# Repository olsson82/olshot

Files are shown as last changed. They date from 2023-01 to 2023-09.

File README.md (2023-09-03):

# OlShot
This is an Arduino based Shooting game system. Free to use, you need to make the components your self.

It's wireless and uses nrf24l01 modules to communicate to the targets and the main system.

## How mutch does it cost to buid ?
Well it will cost you some money, for the components, and maufactoring the pcb, **BUT** to have your custom build game is priceless.

## Many Targets
If you are going to use many targets, you need to redesign main unit pcb to work with **ATmega2560** chip (same as in Arduino Mega)
The code here is by default set for 5 targets, but you can adjust it. Test the code in Arduino software when you change to see if your amount of targets
is accepted.

# Read more
* [Wiki](https://github.com/olsson82/olshot/wiki)
* [Targets](page/targets.md)
* [Main Unit](page/mainunit.md)

## Updates
**2023-09-01: Did a redesign on the Nextion Screen. Files uploaded**

**2023-08-31: The clock function is now added to the code, and some adjustments done in the code**

**2023-08-30: The first BETA version of main unit is released.**

**2023-08-04: Working on the code for main unit and design for the touchscreen.**

### Main Unit
**2023-08-01: Kicad files now uploaded**

**2023-07-31: The main unit has been tested and everything seems to be working. The kicad files will soon be uploaded.**

<figure>
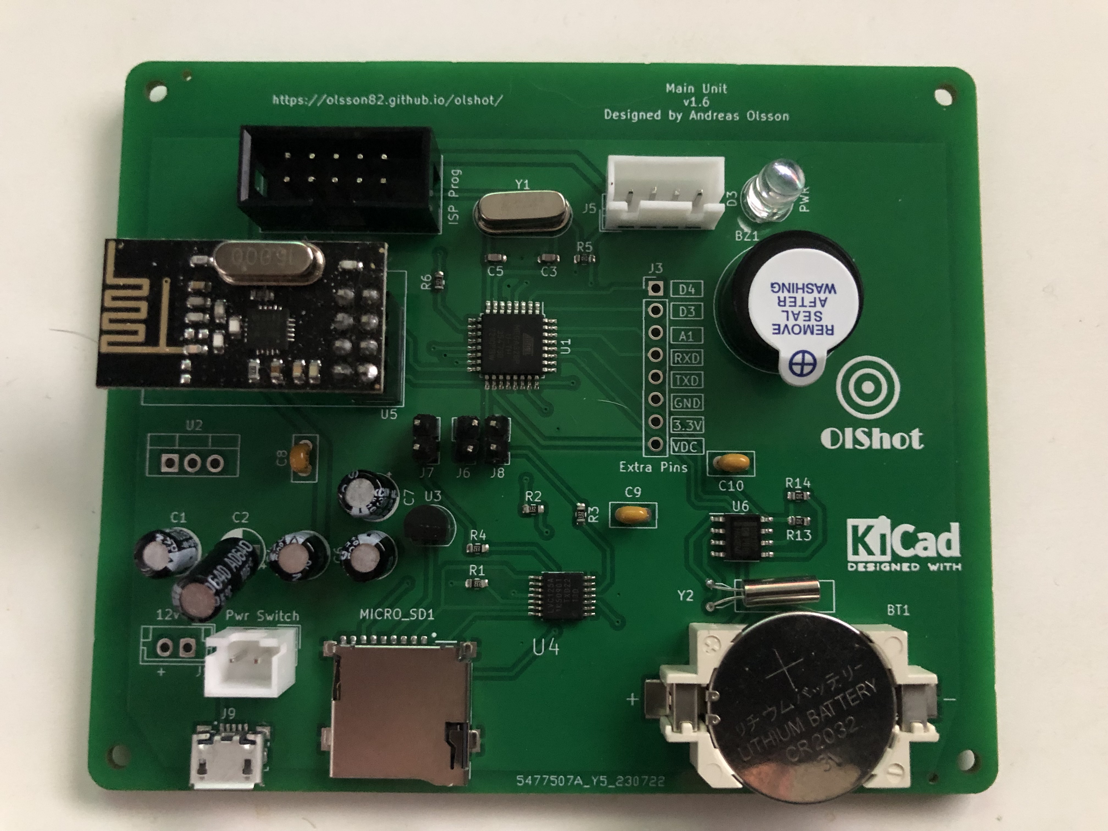
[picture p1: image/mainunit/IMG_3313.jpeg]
    
    <figcaption>Front side of the PCB.</figcaption>
</figure>

### Target PCB
**2023-02-05: The Target PCB Is now avalible for kicad and arduino code.**

Did a redesign of the target sensor, everything is now on the top side. Added jst connections instead of soldering.
<figure>
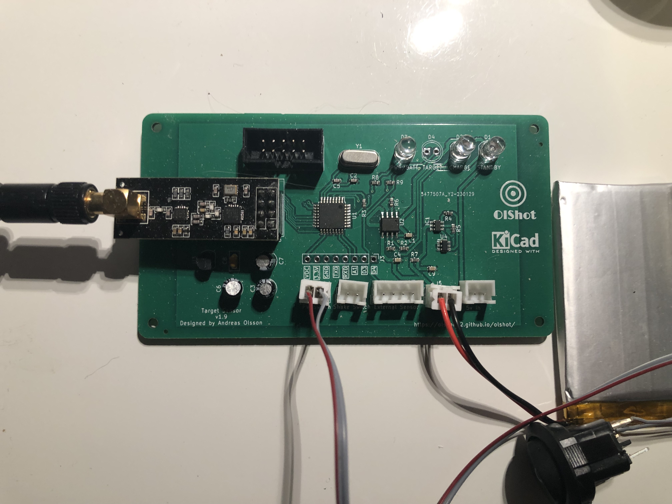
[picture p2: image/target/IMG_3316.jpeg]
    
    <figcaption>Front side of the PCB.</figcaption>
</figure>

## Discuss
Feel free to take part in this project. Go to [Discussion](https://github.com/olsson82/olshot/discussions) to ask questions or discuss about the project.

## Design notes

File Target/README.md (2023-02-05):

# Target Sensor Code
This is the target sensor code. When uploading with the ISP programmer, select Arduino Nano as board and programmer USBasp, then under sketch use **upload with programmer**

Change **targID** and **sendID** to unique id numbers.

During test you can have **#define DEBUG** enabled for serial output. Not recommended when you are going to use the sensors live.

If you need to change the fail safe time change in **myDesiredTime**

During test have the **PALevel** set to **RF24_PA_MIN** and then you can use **RF24_PA_MAX** when you go live. When you have them close during test, it is recommended to have them on min.

## Your code
If you have other version of the target sensor, share them with us.

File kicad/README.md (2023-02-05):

# Kicad Files

This is the place you will find KiCad files.

They are designed in KiCad 6

Inside Library folder you find custom footprints that needed. 

## Use of files
You are free to do changes and copy to your custom builds if you want.

You can also use them without changes. You are not allowed to use my design as is to make money on it.

There a lot of hours spent on develop this so, use it but don't be a millionare on it.

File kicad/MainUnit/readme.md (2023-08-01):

# Main Unit
This is the main unit. You also need target sensors for it to work.
Please read the WIKI about this main unit before manufactor so you know everything.

Good luck!

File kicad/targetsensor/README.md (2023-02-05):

# Target Sensor
This is the target sensor. You also need the main unit for it to work.
Please read the WIKI about this sensors before manufactor so you know everything.

Good luck!

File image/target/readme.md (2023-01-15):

# Image for targets

Here is a place for image for target sensors.

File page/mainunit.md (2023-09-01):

# Main Unit

The main unit is the big brain in all this. It is based on the ATmega328 chip that you will find in example arduino nano. The main unit has:

* SD Card Reader
* USB Powered (Runs from powerbank)
* Nextion display (For all controls)
* Buzzer
* Built in RTC for time.

## How it works
You control everything from the Nextion Display. You can setup all settings from the Settings Page, like targets, how many players and so on.
Select a game and start playing. The main unit will send out to the right target to get ready for the hit mode. When target is returning, a new target will be selected.

Targets are selected randomly, so you never know what target will light. Also in Quicktime mode the time is randomly selected so you don't know when the new target will light up.

## The Games
There are three games to play:

### Quicktime
You can have up to 10 rounds, and you need to shoot fast when the target lights up. The time between the rounds are randomly selected. Shoot fast!

### Rapidfire
You set the total shots needed, then you need to shoot fast! So if you set 20 shots, you need to shoot them realy fast!

### Timed mode
You set the time to play, then shot so many targets you can on that time.

## PCB
All files for manufacture is avalible and the main unit will look like this:

<figure>
    Main Unit
    <figcaption>The Main Unit PCB.</figcaption>
</figure>

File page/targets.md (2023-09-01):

# Wireless Targets

The wireless targets are battery powered and runs on LiPo battery. They use ATMega328P-AU Chip that is in arduino nano. But you can use any Arduino.

## How it works
When the main unit trigger the target sensor, they will wait until vibration starts from an vibration sensor. Normaly you place it on behind the target. And they will send back that they have been trigged.

Each sensor has it unique code, one for recive data, and one for send data, so they know when they are going to be activated.

When the main unit trigger the sensor a **blue** light will be activated, to inform the shooter that it is time to shoot.

## PCB
All files for making the target sensor is avalible and it will look like this:

<figure>
    Target Sensor
    <figcaption>The Target Sensor PCB.</figcaption>
</figure>

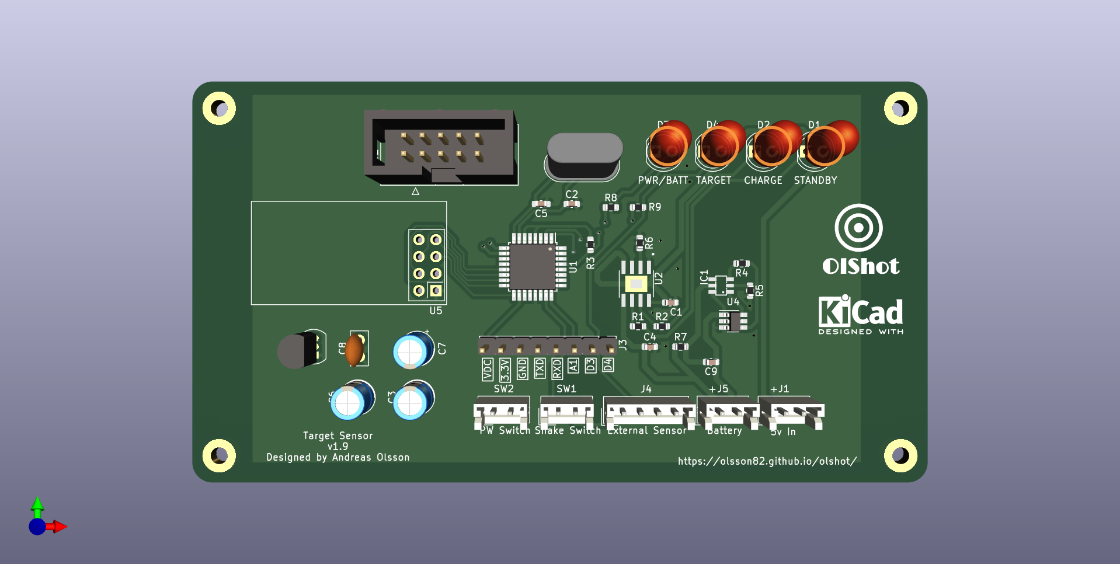
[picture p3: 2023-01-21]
image/target/targetsensor-front.png

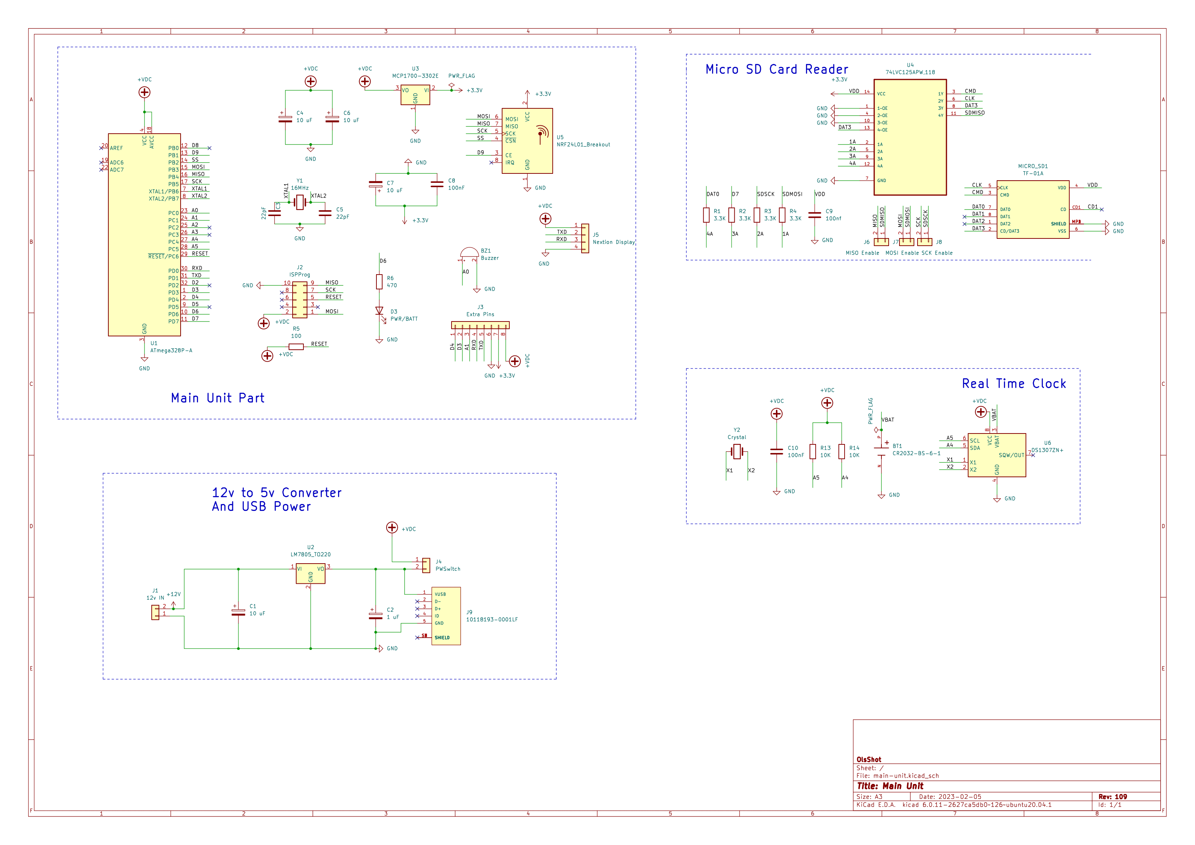
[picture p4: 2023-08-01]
image/mainunit/mainunit.png

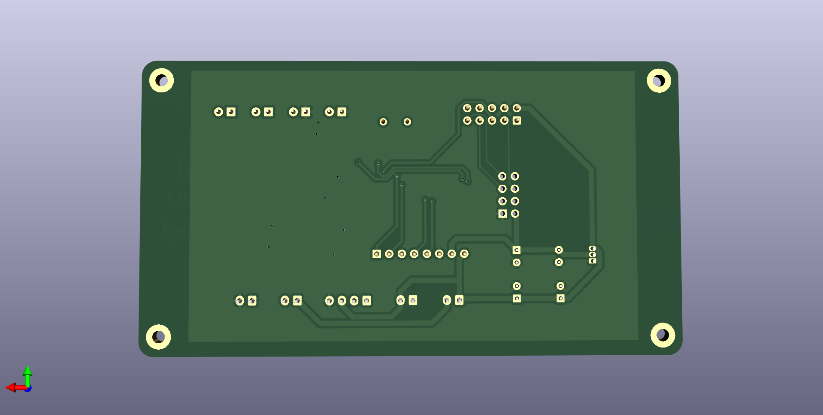
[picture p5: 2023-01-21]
image/target/targetsensor-back.png

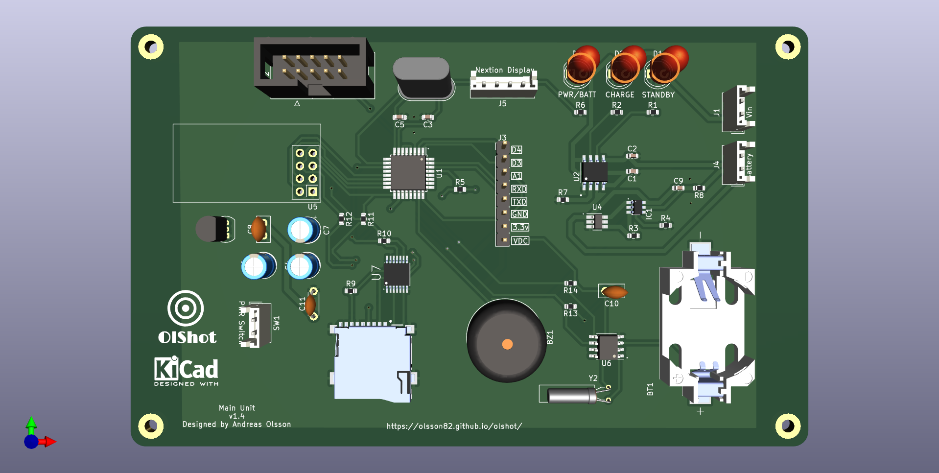
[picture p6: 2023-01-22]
image/mainunit/main-unit.png

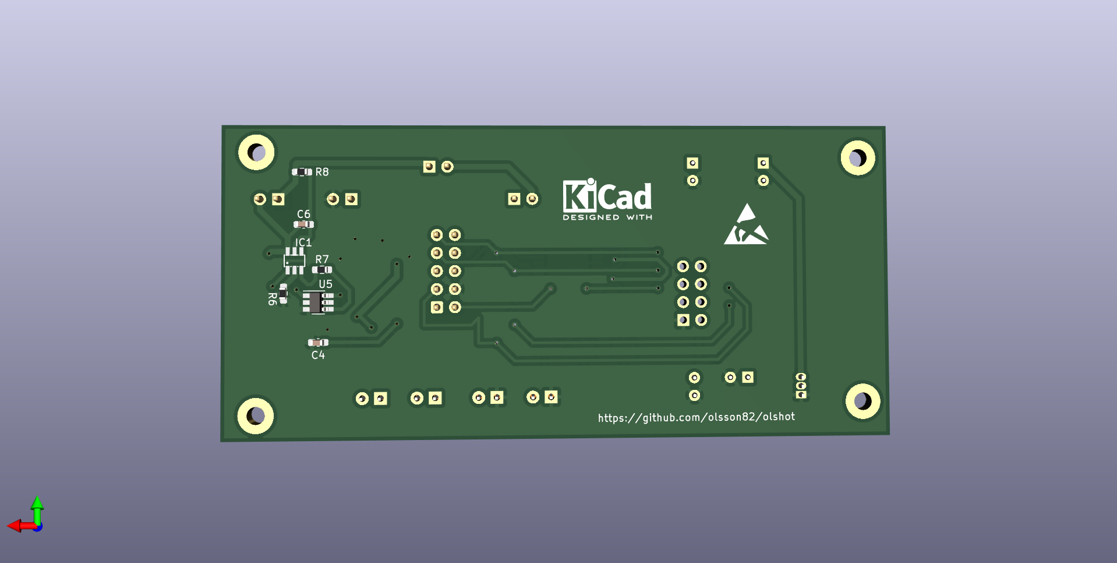
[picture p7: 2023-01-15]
image/target/shootingsensor_back.png

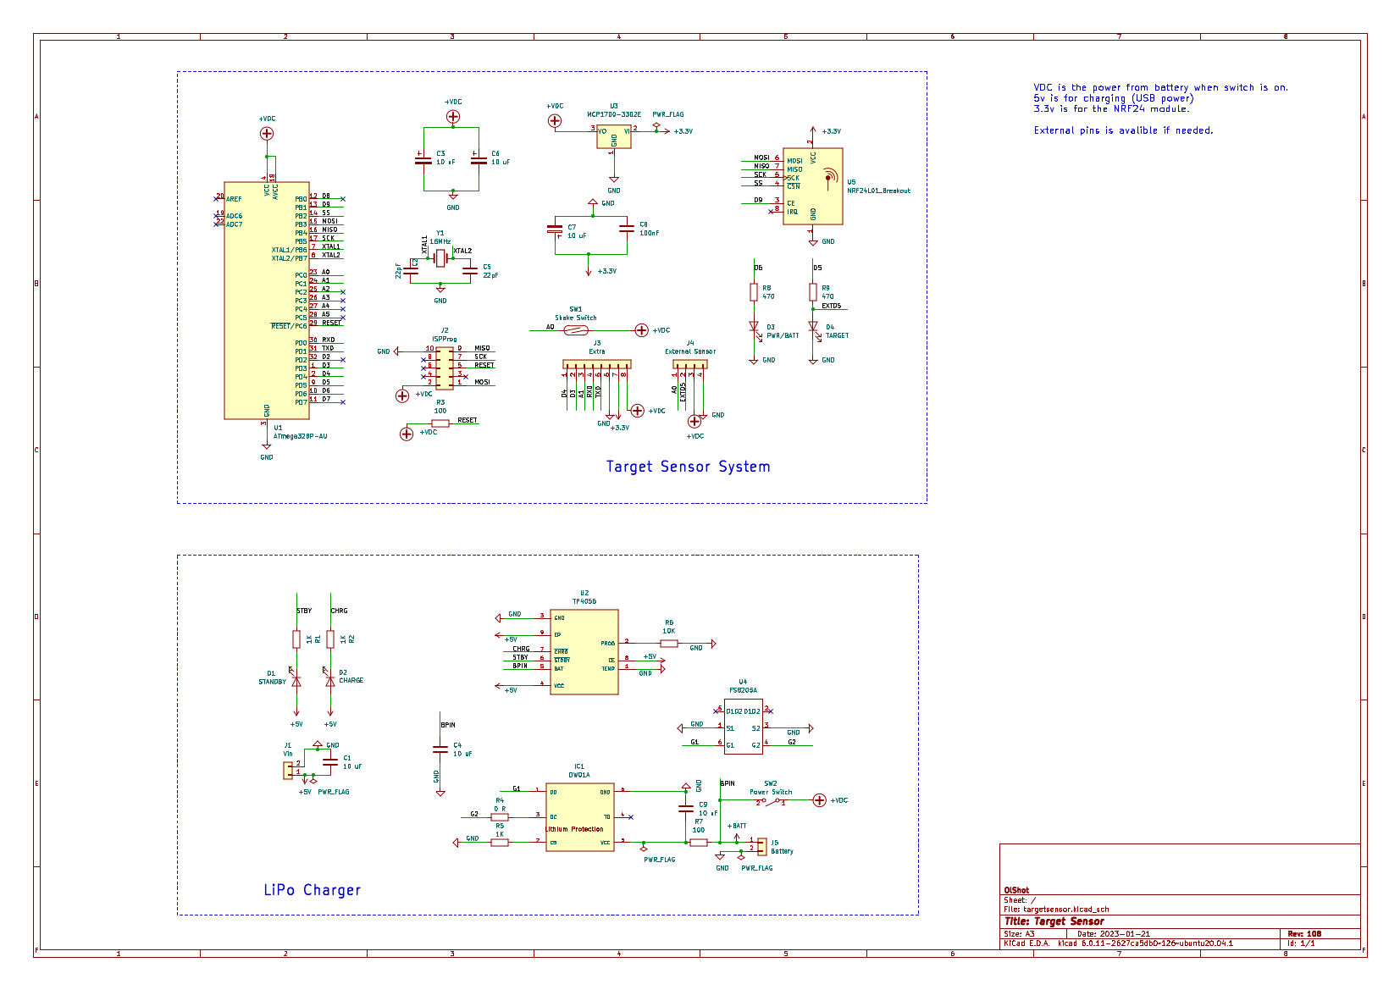
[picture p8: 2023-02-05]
image/target/targetsensor.png

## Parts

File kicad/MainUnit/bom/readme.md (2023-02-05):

# Soldering helper.
An helper for you when you soldering the board.

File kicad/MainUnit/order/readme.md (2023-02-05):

# For order
If you just need to order pcb this files is what you need.

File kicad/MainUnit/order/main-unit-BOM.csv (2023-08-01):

Comment | Designator | Footprint | LCSC Part Number
CR2032-BS-6-1 | BT1 | BAT_CR2032-BS-6-1 | C70377
22pF | C3,C5 | Capacitor_SMD:C_0603_1608Metric | C1653
10118193-0001LF | J9 | 10118193-0001LF:FCI_10118193-0001LF | C381144
TF-01A | MICRO_SD1 | TF-01A | C91145
3.3K | R1,R2,R3,R4 | Resistor_SMD:R_0603_1608Metric | C22978
10K | R13,R14 | Resistor_SMD:R_0603_1608Metric | C25804
100 | R5 | Resistor_SMD:R_0603_1608Metric | C22775
470 | R6 | Resistor_SMD:R_0603_1608Metric | C23179
ATmega328P-A | U1 | Package_QFP:TQFP-32_7x7mm_P0.8mm | C14877
74LVC125APW,118 | U4 | 74LVC125APW_118:SOP65P640X110-14N | C6059
DS1307ZN+ | U6 | Package_SO:SOIC-8_3.9x4.9mm_P1.27mm | C356706

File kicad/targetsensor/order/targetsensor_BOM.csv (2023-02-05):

Comment | Designator | Footprint | LCSC Part Number
10 uF | C1,C4,C9 | Capacitor_SMD:C_0603_1608Metric | C96446
22pF | C2,C5 | Capacitor_SMD:C_0603_1608Metric | C1653
DW01A | IC1 | SOT23-6 | C181096
1K | R1,R2,R5 | Resistor_SMD:R_0603_1608Metric | C21190
100 | R3,R7 | Resistor_SMD:R_0603_1608Metric | C22775
0 R | R4 | Resistor_SMD:R_0603_1608Metric | C21189
10K | R6 | Resistor_SMD:R_0603_1608Metric | C25804
470 | R8,R9 | Resistor_SMD:R_0603_1608Metric | C23179
ATmega328P-A | U1 | Package_QFP:TQFP-32_7x7mm_P0.8mm | C14877
TP4056 | U2 | SOP127P600X175-9N | C16581
FS8205A | U4 | Package_TO_SOT_SMD:SOT-23-6 | C2830320

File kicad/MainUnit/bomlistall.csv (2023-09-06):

Component Count: | 39
Ref | Qnty | Value | Cmp name | Footprint | Description
BT1, | 1 | CR2032-BS-6-1 | CR2032-BS-6-1 | BAT_CR2032-BS-6-1
BZ1, | 1 | Buzzer | Buzzer | Buzzer_Beeper:Buzzer_15x7.5RM7.6 | Buzzer, polarized
C1, C4, C6, C7, | 4 | 10 uF | C_Polarized | Capacitor_THT:CP_Radial_D5.0mm_P2.50mm | Polarized capacitor
C2, | 1 | 1 uF | C_Polarized | Capacitor_THT:CP_Radial_D5.0mm_P2.50mm | Polarized capacitor
C3, C5, | 2 | 22pF | C | Capacitor_SMD:C_0603_1608Metric | Unpolarized capacitor
C8, C10, | 2 | 100nF | C | Capacitor_THT:C_Disc_D5.0mm_W2.5mm_P2.50mm | Unpolarized capacitor
C9, | 1 | 100nf | C | Capacitor_THT:C_Disc_D5.0mm_W2.5mm_P2.50mm | Unpolarized capacitor
D3, | 1 | PWR/BATT | LED | LED_THT:LED_D5.0mm | Light emitting diode
J1, | 1 | 12v IN | Conn_01x02 | Connector_JST:JST_EH_B2B-EH-A_1x02_P2.50mm_Vertical | Generic connector, single row, 01x02, script generated (kicad-library-utils/schlib/autogen/connector/)
J2, | 1 | ISPProg | Conn_02x05_Odd_Even | Connector_IDC:IDC-Header_2x05_P2.54mm_Vertical | Generic connector, double row, 02x05, odd/even pin numbering scheme (row 1 odd numbers, row 2 even numbers), script generated (kicad-library-utils/schlib/autogen/connector/)
J3, | 1 | Extra Pins | Conn_01x08 | Connector_PinHeader_2.54mm:PinHeader_1x08_P2.54mm_Vertical | Generic connector, single row, 01x08, script generated (kicad-library-utils/schlib/autogen/connector/)
J4, | 1 | PWSwitch | Conn_01x02 | Connector_JST:JST_EH_B2B-EH-A_1x02_P2.50mm_Vertical | Generic connector, single row, 01x02, script generated (kicad-library-utils/schlib/autogen/connector/)
J5, | 1 | Nextion Display | Conn_01x04 | Connector_JST:JST_EH_B4B-EH-A_1x04_P2.50mm_Vertical | Generic connector, single row, 01x04, script generated (kicad-library-utils/schlib/autogen/connector/)
J6, | 1 | MISO Enable | Conn_01x02 | Connector_PinHeader_2.54mm:PinHeader_1x02_P2.54mm_Vertical | Generic connector, single row, 01x02, script generated (kicad-library-utils/schlib/autogen/connector/)
J7, | 1 | MOSI Enable | Conn_01x02 | Connector_PinHeader_2.54mm:PinHeader_1x02_P2.54mm_Vertical | Generic connector, single row, 01x02, script generated (kicad-library-utils/schlib/autogen/connector/)
J8, | 1 | SCK Enable | Conn_01x02 | Connector_PinHeader_2.54mm:PinHeader_1x02_P2.54mm_Vertical | Generic connector, single row, 01x02, script generated (kicad-library-utils/schlib/autogen/connector/)
J9, | 1 | 10118193-0001LF | 10118193-0001LF | 10118193-0001LF:FCI_10118193-0001LF
MICRO_SD1, | 1 | TF-01A | TF-01A | TF-01A
R1, R2, R3, R4, | 4 | 3.3K | R | Resistor_SMD:R_0603_1608Metric | Resistor
R5, | 1 | 100 | R | Resistor_SMD:R_0603_1608Metric | Resistor
R6, | 1 | 470 | R | Resistor_SMD:R_0603_1608Metric | Resistor
R13, R14, | 2 | 10K | R | Resistor_SMD:R_0603_1608Metric | Resistor
U1, | 1 | ATmega328P-A | ATmega328P-A | Package_QFP:TQFP-32_7x7mm_P0.8mm | 20MHz, 32kB Flash, 2kB SRAM, 1kB EEPROM, TQFP-32
U2, | 1 | LM7805_TO220 | LM7805_TO220 | Package_TO_SOT_THT:TO-220-3_Vertical | Positive 1A 35V Linear Regulator, Fixed Output 5V, TO-220
U3, | 1 | MCP1700-3302E | MCP1700x-330xxTO | Package_TO_SOT_THT:TO-92_Inline | 250mA Low Quiscent Current LDO, 3.3V output, TO-92
U4, | 1 | 74LVC125APW,118 | 74LVC125APW,118 | 74LVC125APW_118:SOP65P640X110-14N
U5, | 1 | NRF24L01_Breakout | NRF24L01_Breakout | RF_Module:nRF24L01_Breakout | Ultra low power 2.4GHz RF Transceiver, Carrier PCB
U6, | 1 | DS1307ZN+ | DS1307ZN+ | Package_SO:SOIC-8_3.9x4.9mm_P1.27mm | 64 x 8, Serial, I2C Real-time clock, 4.5V to 5.5V VCC, -40°C to +85°C, SOIC-8
Y1, | 1 | 16MHz | Crystal | Crystal:Crystal_HC18-U_Vertical | Two pin crystal
Y2, | 1 | 32.768kHz | Crystal | Crystal:Crystal_AT310_D3.0mm_L10.0mm_Horizontal | Two pin crystal

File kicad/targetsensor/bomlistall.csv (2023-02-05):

Component Count: | 36
Ref | Qnty | Value | Cmp name | Footprint | Description | Vendor
C1, C4, C9, | 3 | 10 uF | C | Capacitor_SMD:C_0603_1608Metric | Unpolarized capacitor
C2, C5, | 2 | 22pF | C | Capacitor_SMD:C_0603_1608Metric | Unpolarized capacitor
C3, C6, C7, | 3 | 10 uF | C_Polarized | Capacitor_THT:CP_Radial_D5.0mm_P2.50mm | Polarized capacitor
C8, | 1 | 100nF | C | Capacitor_THT:C_Disc_D5.0mm_W2.5mm_P2.50mm | Unpolarized capacitor
D1, | 1 | STANDBY | LED | LED_THT:LED_D5.0mm | Light emitting diode
D2, | 1 | CHARGE | LED | LED_THT:LED_D5.0mm | Light emitting diode
D3, | 1 | PWR/BATT | LED | LED_THT:LED_D5.0mm | Light emitting diode
D4, | 1 | TARGET | LED | LED_THT:LED_D5.0mm | Light emitting diode
IC1, | 1 | DW01A | DW01A | SOT23-6
J1, | 1 | Vin | Conn_01x02 | Connector_JST:JST_EH_B2B-EH-A_1x02_P2.50mm_Vertical | Generic connector, single row, 01x02, script generated (kicad-library-utils/schlib/autogen/connector/)
J2, | 1 | ISPProg | Conn_02x05_Odd_Even | Connector_IDC:IDC-Header_2x05_P2.54mm_Vertical | Generic connector, double row, 02x05, odd/even pin numbering scheme (row 1 odd numbers, row 2 even numbers), script generated (kicad-library-utils/schlib/autogen/connector/)
J3, | 1 | Extra | Conn_01x08 | Connector_PinHeader_2.54mm:PinHeader_1x08_P2.54mm_Vertical | Generic connector, single row, 01x08, script generated (kicad-library-utils/schlib/autogen/connector/)
J4, | 1 | External Sensor | Conn_01x04 | Connector_JST:JST_EH_B4B-EH-A_1x04_P2.50mm_Vertical | Generic connector, single row, 01x04, script generated (kicad-library-utils/schlib/autogen/connector/)
J5, | 1 | Battery | Conn_01x02 | Connector_JST:JST_EH_B2B-EH-A_1x02_P2.50mm_Vertical | Generic connector, single row, 01x02, script generated (kicad-library-utils/schlib/autogen/connector/)
R1, R2, R5, | 3 | 1K | R | Resistor_SMD:R_0603_1608Metric | Resistor
R3, R7, | 2 | 100 | R | Resistor_SMD:R_0603_1608Metric | Resistor
R4, | 1 | 0 R | R | Resistor_SMD:R_0603_1608Metric | Resistor
R6, | 1 | 10K | R | Resistor_SMD:R_0603_1608Metric | Resistor
R8, R9, | 2 | 470 | R | Resistor_SMD:R_0603_1608Metric | Resistor
SW1, | 1 | Shake Switch | SW_Reed | Connector_JST:JST_EH_B2B-EH-A_1x02_P2.50mm_Vertical | reed switch
SW2, | 1 | Power Switch | SW_SPST | Connector_JST:JST_EH_B2B-EH-A_1x02_P2.50mm_Vertical | Single Pole Single Throw (SPST) switch
U1, | 1 | ATmega328P-AU | ATmega328P-A | Package_QFP:TQFP-32_7x7mm_P0.8mm | 20MHz, 32kB Flash, 2kB SRAM, 1kB EEPROM, TQFP-32
U2, | 1 | TP4056 | TP4056 | SOP127P600X175-9N
U3, | 1 | MCP1700-3302E | MCP1700x-330xxTO | Package_TO_SOT_THT:TO-92_Inline | 250mA Low Quiscent Current LDO, 3.3V output, TO-92
U4, | 1 | FS8205A | FS8205A | Package_TO_SOT_SMD:SOT-23-6 | FS8205A
U5, | 1 | NRF24L01_Breakout | NRF24L01_Breakout | RF_Module:nRF24L01_Breakout | Ultra low power 2.4GHz RF Transceiver, Carrier PCB
Y1, | 1 | 16MHz | Crystal | Crystal:Crystal_HC18-U_Vertical | Two pin crystal

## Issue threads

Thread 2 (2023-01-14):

PCB For Shooting Sensors

olsson82, 2023-01-14:
# PCB
Make an PCB for the shooting sensor, with built in lipo charger.

olsson82, 2023-01-14:
NRF24 Will be module based, so it possible to choose with or without external antenna.

olsson82, 2023-01-18:
Add some extra connections for pins, and battery contact.

olsson82, 2023-02-05:
Work on it is done!

Closed 2023-02-05.

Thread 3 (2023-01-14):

Develop of Target Sensors

olsson82, 2023-01-14:
Develop the arduino code for the target sensors. They communicate thru nrf24 modules wireless.

olsson82, 2023-01-14:
Started working on the code, not done yet but a part of it is here. 230d5bd9a5e34640cc30d04f9cab19dd336314a9

olsson82, 2023-02-05:
The code is now avalible 1b19e92

Closed 2023-02-05.

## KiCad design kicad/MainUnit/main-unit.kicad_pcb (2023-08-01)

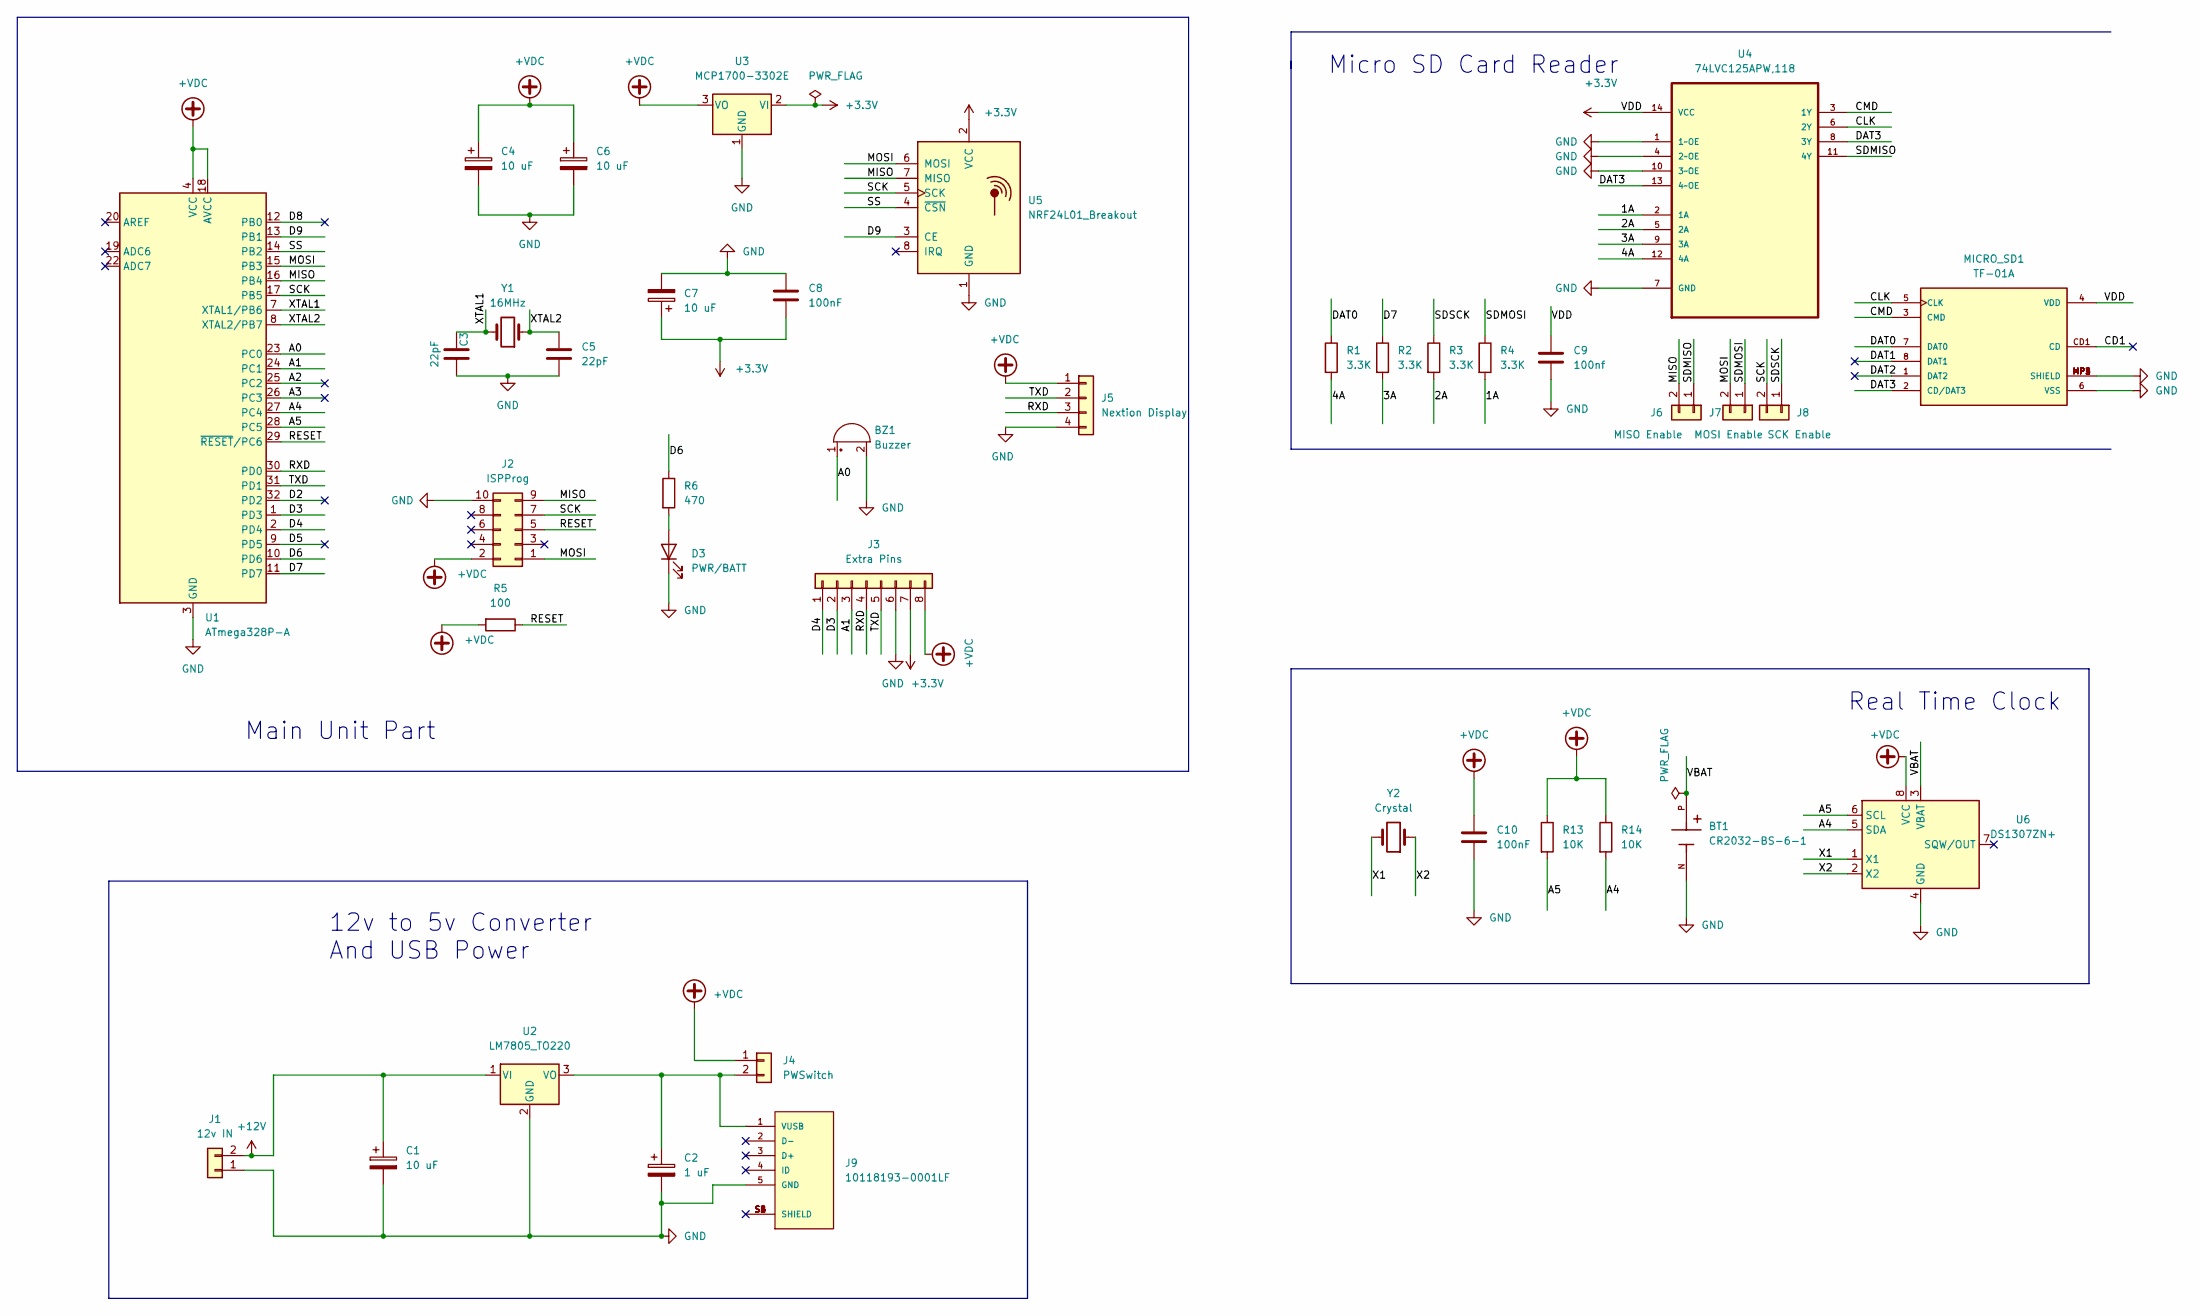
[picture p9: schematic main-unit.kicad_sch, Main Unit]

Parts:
BT1: CR2032-BS-6-1; BAT_CR2032-BS-6-1; PARTREV 2011/2/14; LCSC C70377
BZ1: Buzzer; Buzzer_15x7.5RM7.6
C1, C4, C6, C7: 10 uF; CP_Radial_D5.0mm_P2.50mm
C2: 1 uF; CP_Radial_D5.0mm_P2.50mm
C3, C5: 22pF; C_0603_1608Metric; LCSC C1653
C8, C10: 100nF; C_Disc_D5.0mm_W2.5mm_P2.50mm
C9: 100nf; C_Disc_D5.0mm_W2.5mm_P2.50mm
D3: PWR/BATT; LED_D5.0mm
J1: 12v IN; JST_EH_B2B-EH-A_1x02_P2.50mm_Vertical
J2: ISPProg; IDC-Header_2x05_P2.54mm_Vertical
J3: Extra Pins; PinHeader_1x08_P2.54mm_Vertical
J4: PWSwitch; JST_EH_B2B-EH-A_1x02_P2.50mm_Vertical
J5: Nextion Display; JST_EH_B4B-EH-A_1x04_P2.50mm_Vertical
J6: MISO Enable; PinHeader_1x02_P2.54mm_Vertical
J7: MOSI Enable; PinHeader_1x02_P2.54mm_Vertical
J8: SCK Enable; PinHeader_1x02_P2.54mm_Vertical
J9: 10118193-0001LF; FCI_10118193-0001LF; LCSC C381144
MICRO_SD1: TF-01A; LCSC C91145
R1, R2, R3, R4: 3.3K; R_0603_1608Metric; LCSC C22978
R5: 100; R_0603_1608Metric; LCSC C22775
R6: 470; R_0603_1608Metric; LCSC C23179
R13, R14: 10K; R_0603_1608Metric; LCSC C25804
U1: ATmega328P-A; TQFP-32_7x7mm_P0.8mm; LCSC C14877
U2: LM7805_TO220; TO-220-3_Vertical
U3: MCP1700-3302E; TO-92_Inline
U4: 74LVC125APW,118; SOP65P640X110-14N; MPN 74LVC125APW,118; LCSC C6059
U5: NRF24L01_Breakout; nRF24L01_Breakout
U6: DS1307ZN+; SOIC-8_3.9x4.9mm_P1.27mm; LCSC C356706
Y1: 16MHz; Crystal_HC18-U_Vertical
Y2: Crystal; Crystal_AT310_D3.0mm_L10.0mm_Horizontal

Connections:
+3.3V: C7.1, C8.2, C9.1, J3.7, MICRO_SD1.4 (VDD), U3.2 (VI), U4.14 (VCC), U5.2 (VCC)
+12V: C1.1, J1.2, U2.1 (VI)
+VDC: C4.1, C6.1, C10.2, J2.2, J3.8, J4.1, J5.1, R5.2, R13.1, R14.1, U1.4 (VCC), U1.6 (VCC), U1.18 (AVCC), U3.3 (VO), U6.8 (VCC)
/1A: R4.2, U4.2 (1A)
/2A: R3.2, U4.5 (2A)
/3A: R2.2, U4.9 (3A)
/4A: R1.2, U4.12 (4A)
/A0: BZ1.1 (-), U1.23 (PC0)
/A1: J3.3, U1.24 (PC1)
/A2: U1.25 (PC2)
/A3: U1.26 (PC3)
/A4: R14.2, U1.27 (PC4), U6.5 (SDA)
/A5: R13.2, U1.28 (PC5), U6.6 (SCL)
/CD1: MICRO_SD1.CD1 (CD)
/CLK: MICRO_SD1.5 (CLK), U4.6 (2Y)
/CMD: MICRO_SD1.3 (CMD), U4.3 (1Y)
/D2: U1.32 (PD2)
/D3: J3.2, U1.1 (PD3)
/D4: J3.1, U1.2 (PD4)
/D5: U1.9 (PD5)
/D6: R6.1, U1.10 (PD6)
/D7: R2.1, U1.11 (PD7)
/D8: U1.12 (PB0)
/D9: U1.13 (PB1), U5.3 (CE)
/DAT0: MICRO_SD1.7 (DAT0), R1.1
/DAT1: MICRO_SD1.8 (DAT1)
/DAT2: MICRO_SD1.1 (DAT2)
/DAT3: MICRO_SD1.2 (CD/DAT3), U4.8 (3Y), U4.13 (4~OE)
/MISO: J2.9, J6.2, U1.16 (PB4), U5.7 (MISO)
/MOSI: J2.1, J7.2, U1.15 (PB3), U5.6 (MOSI)
/RESET: J2.5, R5.1, U1.29 (~RESET/PC6)
/RXD: J3.4, J5.3, U1.30 (PD0)
/SCK: J2.7, J8.2, U1.17 (PB5), U5.5 (SCK)
/SDMISO: J6.1, U4.11 (4Y)
/SDMOSI: J7.1, R4.1
/SDSCK: J8.1, R3.1
/SS: U1.14 (PB2), U5.4 (~CSN)
/TXD: J3.5, J5.2, U1.31 (PD1)
/VBAT: BT1.P, U6.3 (VBAT)
/X1: U6.1 (X1), Y2.2
/X2: U6.2 (X2), Y2.1
/XTAL1: C3.1, U1.7 (XTAL1/PB6), Y1.2
/XTAL2: C5.2, U1.8 (XTAL2/PB7), Y1.1
GND: BT1.N, BZ1.2 (+), C1.2, C2.2, C3.2, C4.2, C5.1, C6.2, C7.2, C8.1, C9.2, C10.1, D3.1 (K), J1.1, J2.10, J3.6, J5.4, J9.5 (GND), MICRO_SD1.6 (VSS), MICRO_SD1.MP1 (SHIELD), MICRO_SD1.MP2 (SHIELD), MICRO_SD1.MP3 (SHIELD), MICRO_SD1.MP4 (SHIELD), U1.3 (GND), U1.5 (GND), U1.21 (GND), U2.2 (GND), U3.1 (GND), U4.1 (1~OE), U4.4 (2~OE), U4.7 (GND), U4.10 (3~OE), U5.1 (GND), U6.4 (GND)
unnamed: C2.1, J4.2, J9.1 (VUSB), U2.3 (VO)
unnamed: D3.2 (A), R6.2

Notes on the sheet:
Micro SD Card Reader
Main Unit Part
12v to 5v Converter And USB Power
Real Time Clock

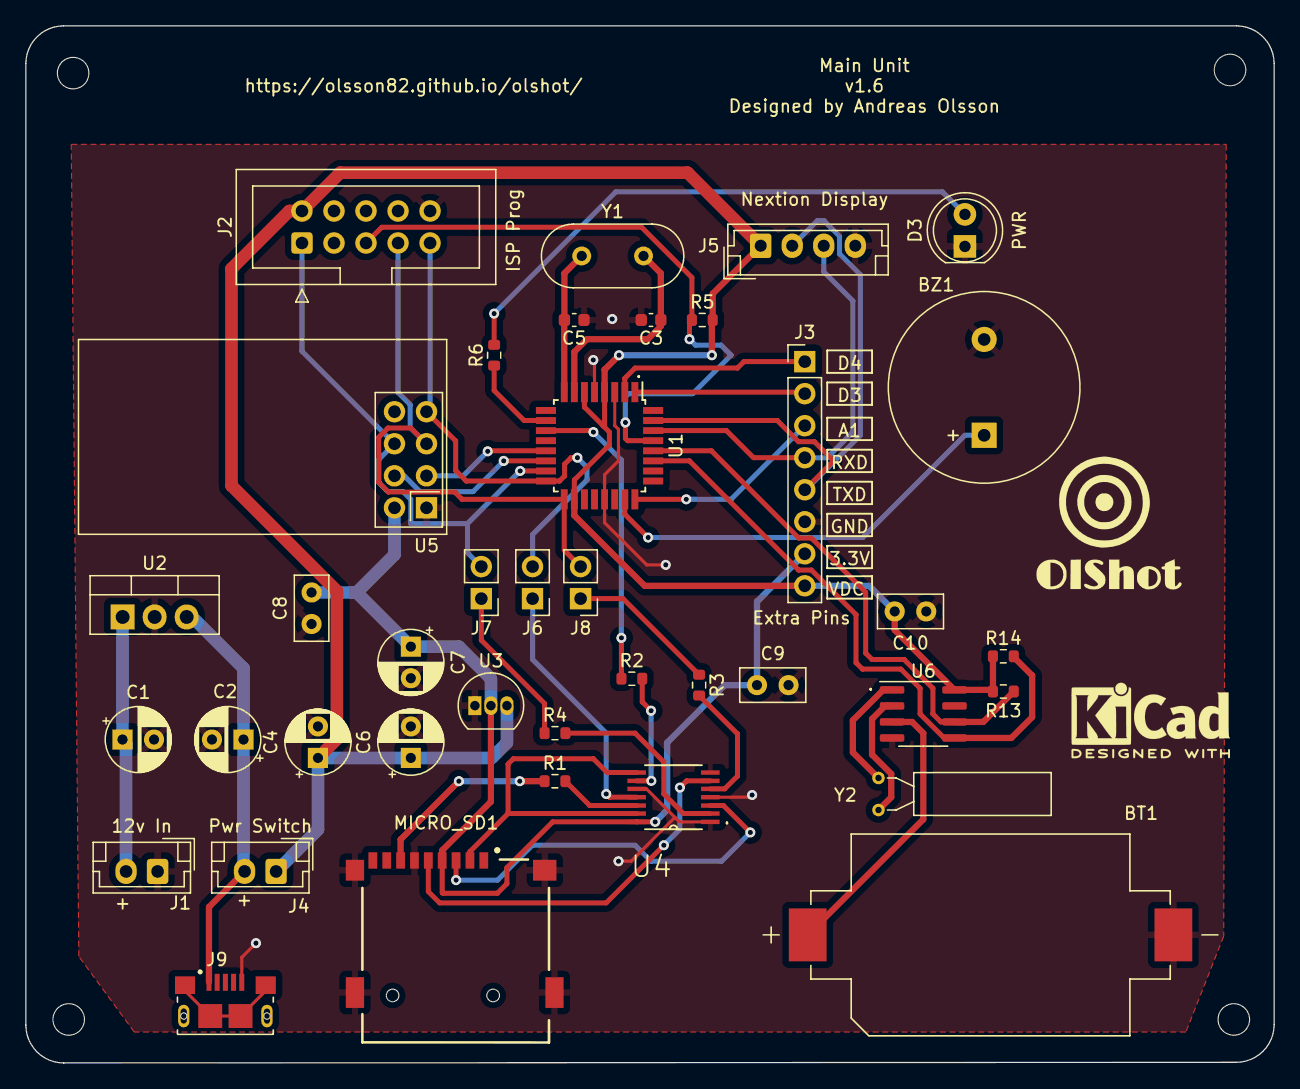
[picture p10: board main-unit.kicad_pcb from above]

Board: 2 copper layers, 99.0 x 82.2 mm, 39 parts (0 on the bottom side), 38 nets.

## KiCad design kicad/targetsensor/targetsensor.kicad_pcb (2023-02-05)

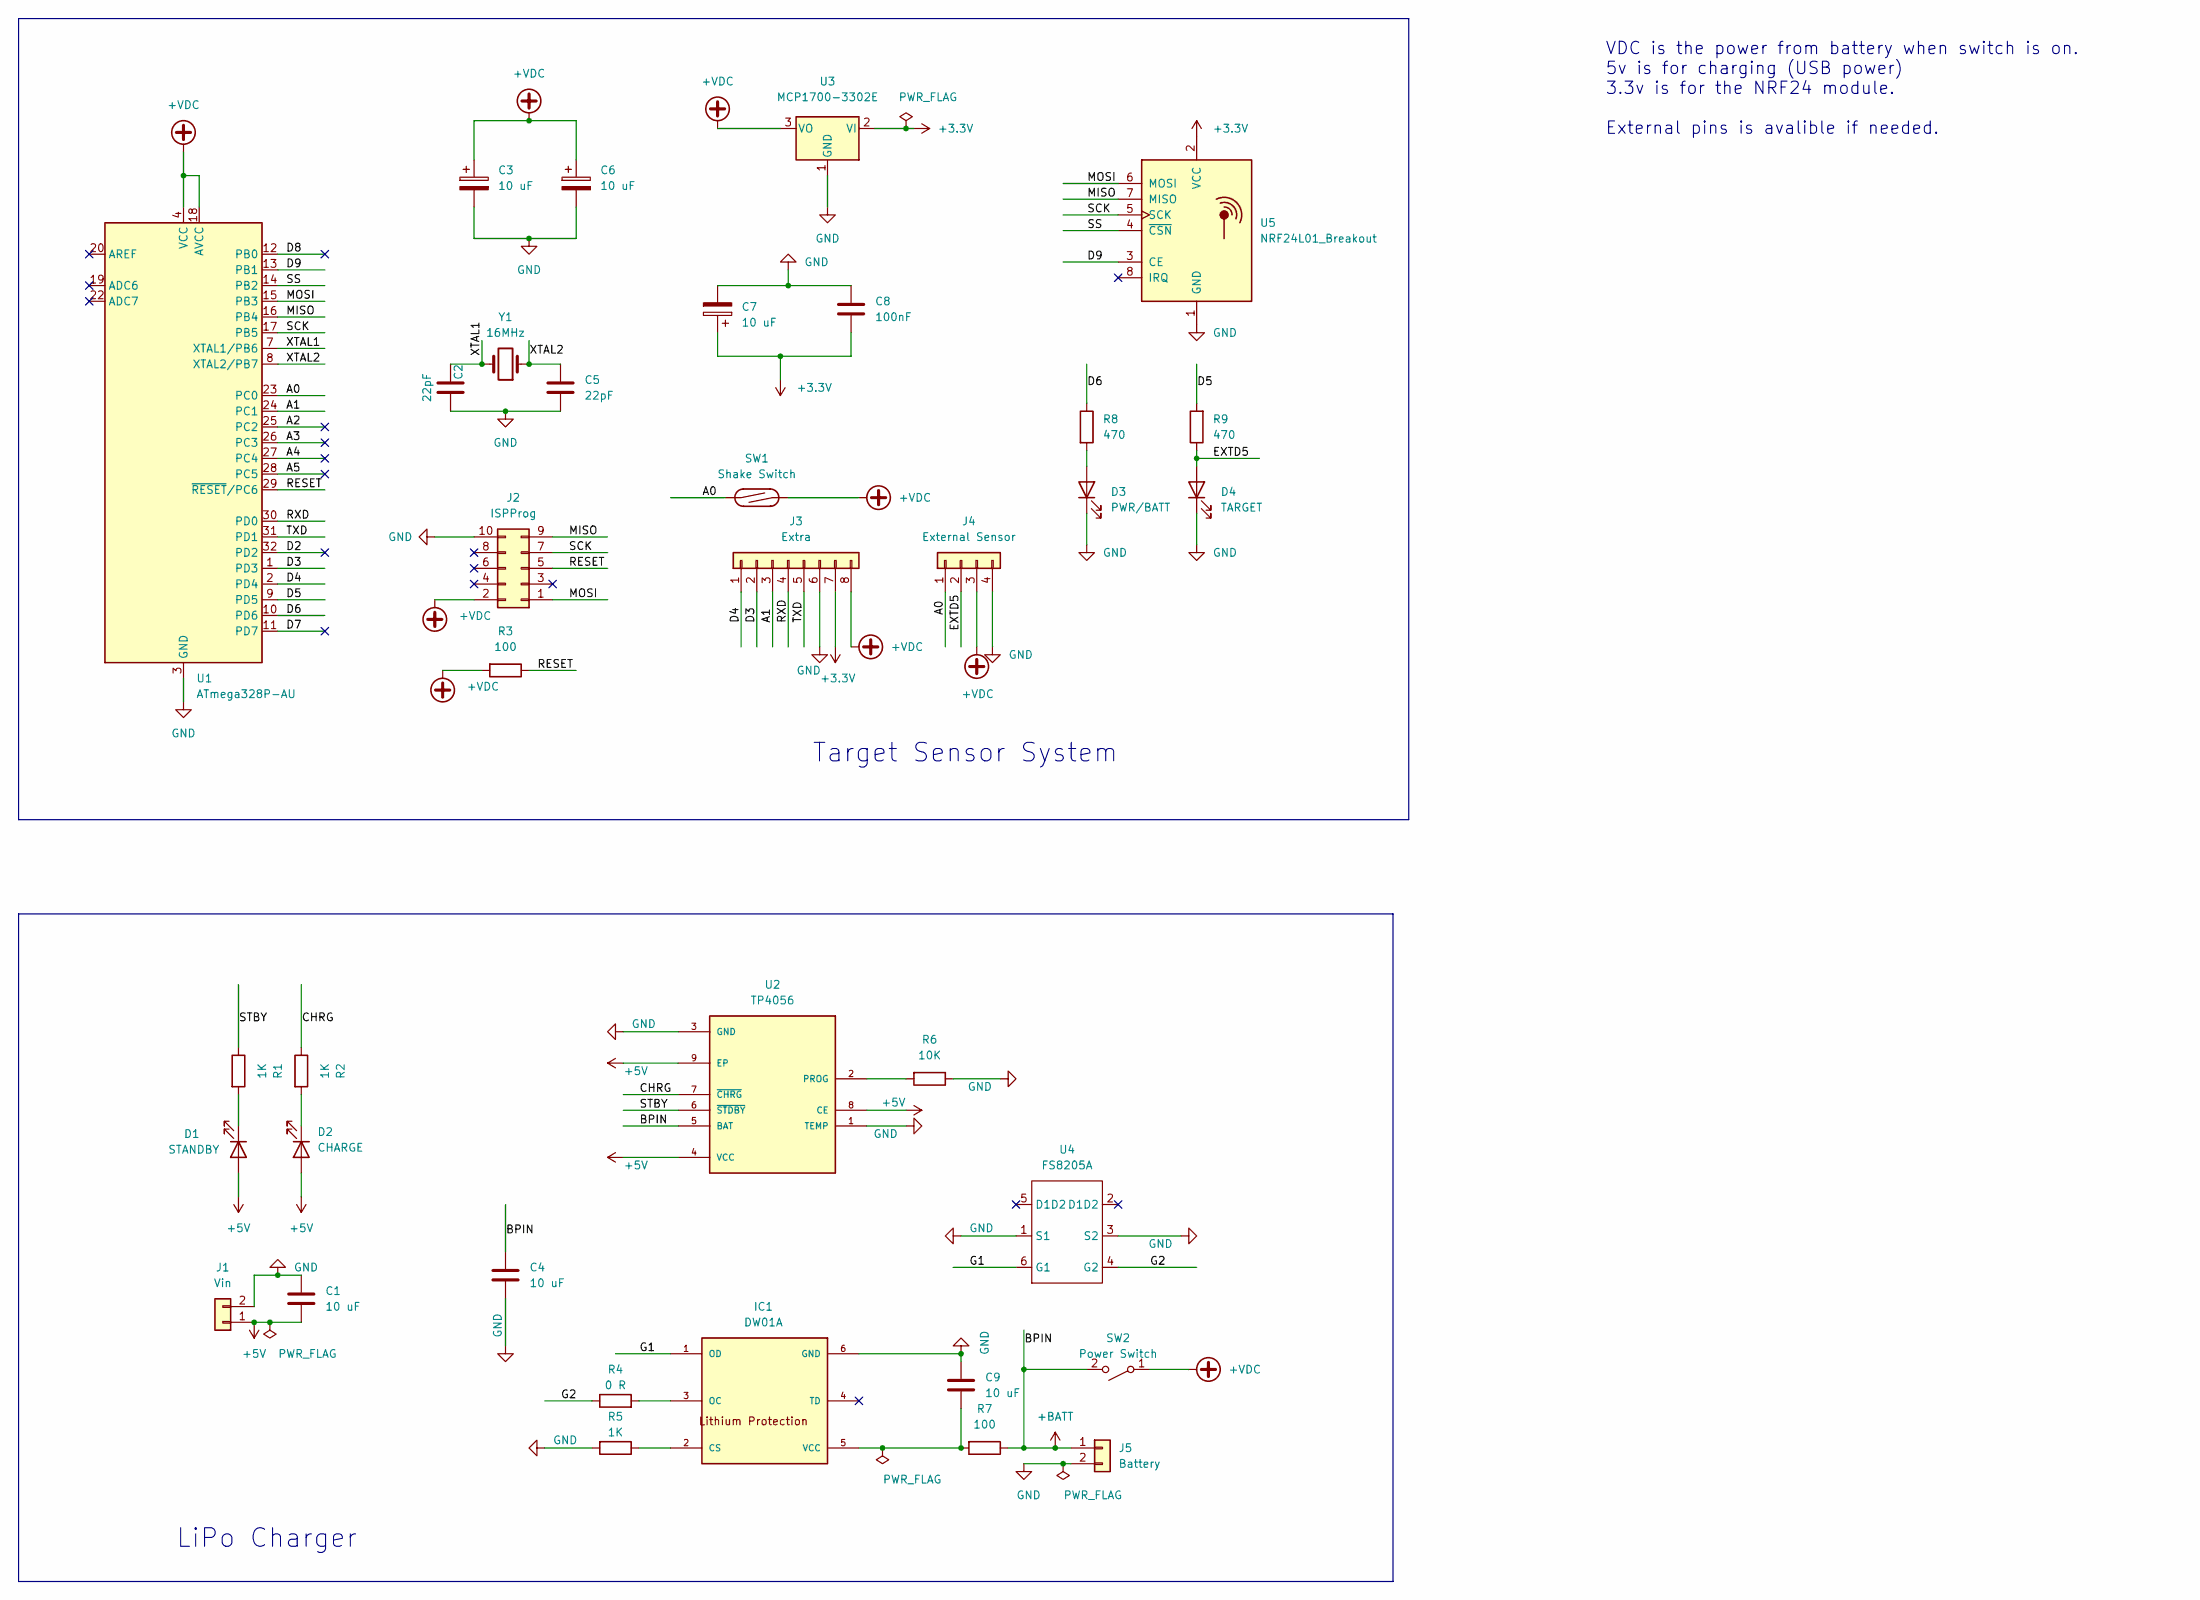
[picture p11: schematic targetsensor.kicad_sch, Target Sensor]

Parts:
C1, C4, C9: 10 uF; C_0603_1608Metric; LCSC C96446
C2, C5: 22pF; C_0603_1608Metric; LCSC C1653
C3, C6, C7: 10 uF; CP_Radial_D5.0mm_P2.50mm
C8: 100nF; C_Disc_D5.0mm_W2.5mm_P2.50mm
D1: STANDBY; LED_D5.0mm
D2: CHARGE; LED_D5.0mm
D3: PWR/BATT; LED_D5.0mm
D4: TARGET; LED_D5.0mm
IC1: DW01A; SOT23-6; MPN DW01A; LCSC C181096
J1: Vin; JST_EH_B2B-EH-A_1x02_P2.50mm_Vertical
J2: ISPProg; IDC-Header_2x05_P2.54mm_Vertical
J3: Extra; PinHeader_1x08_P2.54mm_Vertical
J4: External Sensor; JST_EH_B4B-EH-A_1x04_P2.50mm_Vertical
J5: Battery; JST_EH_B2B-EH-A_1x02_P2.50mm_Vertical
R1, R2, R5: 1K; R_0603_1608Metric; LCSC C21190
R3, R7: 100; R_0603_1608Metric; LCSC C22775
R4: 0 R; R_0603_1608Metric; LCSC C21189
R6: 10K; R_0603_1608Metric; LCSC C25804
R8, R9: 470; R_0603_1608Metric; LCSC C23179
SW1: Shake Switch; JST_EH_B2B-EH-A_1x02_P2.50mm_Vertical
SW2: Power Switch; JST_EH_B2B-EH-A_1x02_P2.50mm_Vertical
U1: ATmega328P-AU; TQFP-32_7x7mm_P0.8mm; LCSC C14877
U2: TP4056; SOP127P600X175-9N; LCSC C16581
U3: MCP1700-3302E; TO-92_Inline
U4: FS8205A; SOT-23-6; LCSC C2830320
U5: NRF24L01_Breakout; nRF24L01_Breakout
Y1: 16MHz; Crystal_HC18-U_Vertical

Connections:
+3.3V: C7.1, C8.2, J3.7, U3.2 (VI), U5.2 (VCC)
+5V: C1.2, D1.2 (A), D2.2 (A), J1.1, U2.4 (VCC), U2.8 (CE), U2.9 (EP)
+BATT: C4.1, J5.1, R7.1, SW2.2 (B), U2.5 (BAT)
+VDC: C3.1, C6.1, J2.2, J3.8, J4.3, R3.2, SW1.2, SW2.1 (A), U1.4 (VCC), U1.6 (VCC), U1.18 (AVCC), U3.3 (VO)
/A0: J4.1, SW1.1, U1.23 (PC0)
/A1: J3.3, U1.24 (PC1)
/A2: U1.25 (PC2)
/A3: U1.26 (PC3)
/A4: U1.27 (PC4)
/A5: U1.28 (PC5)
/CHRG: R2.1, U2.7 (~CHRG)
/D2: U1.32 (PD2)
/D3: J3.2, U1.1 (PD3)
/D4: J3.1, U1.2 (PD4)
/D5: R9.2, U1.9 (PD5)
/D6: R8.1, U1.10 (PD6)
/D7: U1.11 (PD7)
/D8: U1.12 (PB0)
/D9: U1.13 (PB1), U5.3 (CE)
/EXTD5: D4.2 (A), J4.2, R9.1
/G1: IC1.1 (OD), U4.6 (G1)
/G2: R4.1, U4.4 (G2)
/MISO: J2.9, U1.16 (PB4), U5.7 (MISO)
/MOSI: J2.1, U1.15 (PB3), U5.6 (MOSI)
/RESET: J2.5, R3.1, U1.29 (~RESET/PC6)
/RXD: J3.4, U1.30 (PD0)
/SCK: J2.7, U1.17 (PB5), U5.5 (SCK)
/SS: U1.14 (PB2), U5.4 (~CSN)
/STBY: R1.1, U2.6 (~STDBY)
/TXD: J3.5, U1.31 (PD1)
/XTAL1: C2.1, U1.7 (XTAL1/PB6), Y1.2
/XTAL2: C5.2, U1.8 (XTAL2/PB7), Y1.1
GND: C1.1, C2.2, C3.2, C4.2, C5.1, C6.2, C7.2, C8.1, C9.1, D3.1 (K), D4.1 (K), IC1.6 (GND), J1.2, J2.10, J3.6, J4.4, J5.2, R5.2, R6.1, U1.3 (GND), U1.5 (GND), U1.21 (GND), U2.1 (TEMP), U2.3 (GND), U3.1 (GND), U4.1 (S1), U4.3 (S2), U5.1 (GND)
unnamed: C9.2, IC1.5 (VCC), R7.2
unnamed: D1.1 (K), R1.2
unnamed: D2.1 (K), R2.2
unnamed: D3.2 (A), R8.2
unnamed: IC1.2 (CS), R5.1
unnamed: IC1.3 (OC), R4.2
unnamed: R6.2, U2.2 (PROG)

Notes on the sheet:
VDC is the power from battery when switch is on. 5v is for charging (USB power) 3.3v is for the NRF24 module. External pins is avalible if needed.
LiPo Charger
Target Sensor System

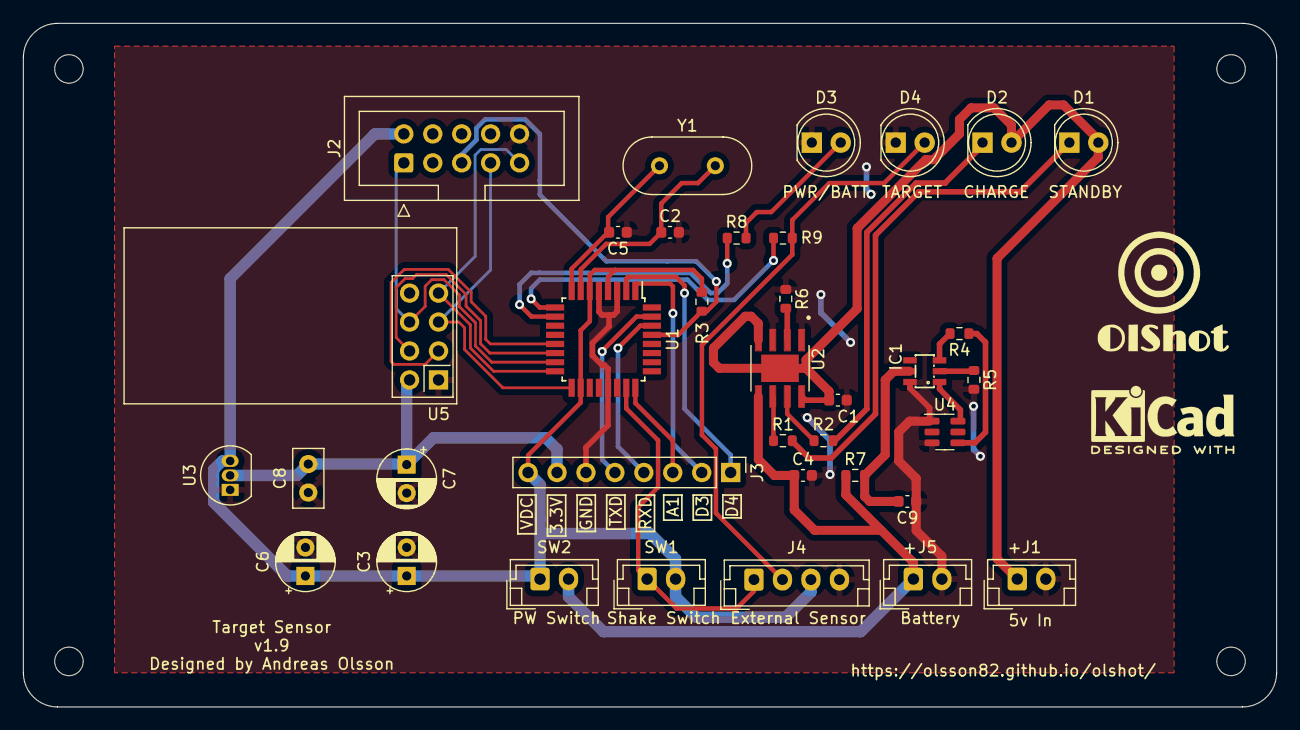
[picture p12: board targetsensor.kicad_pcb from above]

Board: 2 copper layers, 110.0 x 60.0 mm, 36 parts (0 on the bottom side), 33 nets.

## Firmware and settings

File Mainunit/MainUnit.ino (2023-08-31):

//======================================================
//
//   #####   ##       ####  ##   ##   #####   ######
//  ##   ##  ##      ##     ##   ##  ##   ##    ##
//  ##   ##  ##       ###   #######  ##   ##    ##
//  ##   ##  ##         ##  ##   ##  ##   ##    ##
//   #####   ######  ####   ##   ##   #####     ##
//
//======================================================
/**------------------------------------------------------------------------
 * ?                                ABOUT
 * @author         :  Andreas Olsson
 * @email          :  andreas@olsserv82.com
 * @repo           :  https://github.com/olsson82/olshot
 * @updatedOn      :  2023-08-31
 * @description    :  Code for main unit
 *------------------------------------------------------------------------**/
/**----------------------------------------------
 * *                   INFO
 *   Code is still in development, and is a BETA only!
 *
 *---------------------------------------------**/
#include "EasyNextionLibrary.h"
#include <SPI.h>
#include "SdFat.h"
#include "RF24.h"
#include "RTClib.h"
#define CNFFILE "cnf.dat"  //Set filename here
SdFat SD;
RF24 myRadio(9, 10);
EasyNex myNex(Serial);
RTC_DS1307 rtc;
const uint64_t addresses[2] = { 0xF0F0F0F0E1LL, 0xABCDABCD71LL };
struct Config {
  int targets = 5;
  int maxrounds = 5;
  int maxrapid = 10;
  int totalplayer = 2;
  int timed = 10000;
  long safetime = 15000;
  int targID[5] = { 1, 2, 3, 4, 5 };
  int recID[5] = { 6, 7, 8, 9, 10 };
  char p1[11];
  char p2[11];
  char p3[11];
  char p4[11];
  char p5[11];
  char hp1[11];
  char hp2[11];
  char hp3[11];
  char hd1[17];
  char hd2[17];
  char hd3[17];
  float hq[2] = { 0, 0 };
  int hr = 0;
};
Config config;
struct sending {
  int I = 1;                 // The id number for the target
  int J = 0;                 // If it active target or test signal.
  long F = config.safetime;  //Sending the failsafe time
};
typedef struct sending Package;
Package totarget;

struct recived {
  int K = 1;    // The send id number for the target
  int L = 0;    // Is recived
  float O = 1;  //Battery volt
};
typedef struct recived Package1;
Package1 fromtarget;
File myFile;
const int buzzer = A0;
const int LEDPWR = 6;

void setup() {
  pinMode(LEDPWR, OUTPUT);
  digitalWrite(LEDPWR, HIGH);
  if (!SD.begin(7)) {
    digitalWrite(LEDPWR, LOW);
    delay(1000);
    digitalWrite(LEDPWR, HIGH);
    delay(1000);
    digitalWrite(LEDPWR, LOW);
    while (1)
      ;
  }
  if (!myRadio.begin()) {
    digitalWrite(LEDPWR, LOW);
    delay(1000);
    digitalWrite(LEDPWR, HIGH);
    delay(1000);
    digitalWrite(LEDPWR, LOW);
    while (1)
      ;
  }
   if (! rtc.begin()) {
      while (1)
      ;
  } 
  myRadio.setPALevel(RF24_PA_MIN);    //Use min when testing, then change to MAX for better distance.
  myRadio.setDataRate(RF24_250KBPS);  //Better distance if sending low data.
  myRadio.setRetries(15, 15);
  myRadio.setChannel(108);  //Keep abow wifi channels
  myRadio.openReadingPipe(1, addresses[0]);
  myRadio.openWritingPipe(addresses[1]);
  myRadio.startListening();
  delay(100);
  myNex.begin(9600);
  myNex.writeStr(F("page page1"));
  delay(50);
  if (SD.exists(CNFFILE)) {
    conf(0);
  } else {
    conf(1);
  }
}

void loop() {
  myNex.NextionListen();
}

void trigger7() {
  int sys;
  sys = myNex.readNumber("sys0");
  if (sys == 1) {
    config.safetime = myNex.readNumber(F("n4.val"));
    config.maxrapid = myNex.readNumber(F("n0.val"));
    config.timed = myNex.readNumber(F("n2.val"));
    config.maxrounds = myNex.readNumber(F("n1.val"));
    config.targets = myNex.readNumber(F("n3.val"));
  }
  if (sys == 2) {
    for (int ao = 0; ao < 5; ao++) {
      config.targID[ao] = myNex.readNumber("n" + String(ao) + ".val");
      config.recID[ao] = myNex.readNumber("na" + String(ao) + ".val");
    }
  }
  if (sys == 3) {
    config.totalplayer = myNex.readNumber(F("n0.val"));
    myNex.readStr(F("ta0.txt")).toCharArray(config.p1, 11);
    myNex.readStr(F("ta1.txt")).toCharArray(config.p2, 11);
    myNex.readStr(F("ta2.txt")).toCharArray(config.p3, 11);
    myNex.readStr(F("ta3.txt")).toCharArray(config.p4, 11);
    myNex.readStr(F("ta4.txt")).toCharArray(config.p5, 11);
  }
  if (sys == 4) {
    rtc.adjust(DateTime(myNex.readNumber(F("n0.val")), myNex.readNumber(F("n1.val")), myNex.readNumber(F("n2.val")), myNex.readNumber(F("n3.val")), myNex.readNumber(F("n4.val")), myNex.readNumber(F("n5.val"))));
  }
  myNex.writeStr(F("page page2"));
  delay(50);
  conf(1);
}

void trigger2() {
  sendTest(1);
}

void trigger1() {
  play(myNex.readNumber(F("sys1")));
}

void trigger4() {
  myNex.writeNum(F("n4.val"), config.safetime);
  myNex.writeNum(F("n0.val"), config.maxrapid);
  myNex.writeNum(F("n2.val"), config.timed);
  myNex.writeNum(F("n1.val"), config.maxrounds);
  myNex.writeNum(F("n3.val"), config.targets);
}

void trigger5() {
  for (int ao = 0; ao < 5; ao++) {
    myNex.writeNum("n" + String(ao) + ".val", config.targID[ao]);
    myNex.writeNum("na" + String(ao) + ".val", config.recID[ao]);
  }
}

void trigger6() {
  myNex.writeNum(F("n0.val"), config.totalplayer);
  myNex.writeStr(F("ta0.txt"), config.p1);
  myNex.writeStr(F("ta1.txt"), config.p2);
  myNex.writeStr(F("ta2.txt"), config.p3);
  myNex.writeStr(F("ta3.txt"), config.p4);
  myNex.writeStr(F("ta4.txt"), config.p5);
}

void trigger3() {
  myNex.writeStr(F("ta0.txt"), String(config.hq[0]));
  myNex.writeStr(F("ta1.txt"), config.hp1);
  myNex.writeStr(F("ta2.txt"), config.hd1);
  myNex.writeStr(F("ta3.txt"), String(config.hq[1]));
  myNex.writeStr(F("ta4.txt"), config.hp3);
  myNex.writeStr(F("ta5.txt"), config.hd3);
  myNex.writeStr(F("ta6.txt"), String(config.hr));
  myNex.writeStr(F("ta7.txt"), config.hp2);
  myNex.writeStr(F("ta8.txt"), config.hd2);
}

void conf(int set) {
  if (set == 1) {
    SD.remove(CNFFILE);
    myFile = SD.open(CNFFILE, FILE_WRITE);
    if (myFile) {
      const size_t bytesWritten = myFile.write((byte *)&config, sizeof(config));
      myFile.close();
    }
  } else {
    myFile = SD.open(CNFFILE, FILE_READ);
    const size_t bytesRead = myFile.read((byte *)&config, sizeof(config));
    myFile.close();
  }
}

void inform(int buzz, int light, int runs) {
  for (int runn = 0; runn < runs; runn++) {
    if (buzz == 1) {
      tone(buzzer, 1000);
    }
    if (light == 1) {
      digitalWrite(LEDPWR, LOW);
    }
    delay(1000);
    if (buzz == 1) {
      noTone(buzzer);
    }
    if (light == 1) {
      digitalWrite(LEDPWR, HIGH);
    }
    delay(1000);
  }
}

void sendTest(int RunTest) {
  long startTime, stopTime;
  int i;
  int oTargets = config.targets - 1;
  int WaitForResponse = 0;
  while (RunTest == 1) {
    for (i = 0; i <= oTargets; i++) {
      totarget.I = config.targID[i];
      totarget.J = 2;
      myRadio.stopListening();
      delay(100);
      myRadio.write(&totarget, sizeof(totarget));
      delay(100);
      myRadio.startListening();
      WaitForResponse = 1;
      startTime = millis();
      while (WaitForResponse == 1) {
        stopTime = millis();
        if (stopTime - startTime >= config.safetime) {
          WaitForResponse = 0;
          inform(1, 1, 3);
        }
        if (myRadio.available(addresses[0])) {
          myRadio.read(&fromtarget, sizeof(fromtarget));
          if (fromtarget.K == config.recID[i]) {
            myNex.writeStr("page18.bbt" + String(i) + ".txt", String(fromtarget.O));
            WaitForResponse = 0;
            delay(1000);
          }
        }
      }
      if (i >= oTargets) {
        RunTest = 0;
        delay(2000);
        myNex.writeStr(F("page page1"));
      }
    }
  }
}

void play(int g) {
  String pname;
  for (int ao = 0; ao <= config.totalplayer - 1; ao++) {
    myNex.writeStr(F("page page8"));
    delay(50);
    if (ao == 0) {
      myNex.writeStr(F("tnextp.txt"), config.p1);
      pname = config.p1;
    } else if (ao == 1) {
      myNex.writeStr(F("tnextp.txt"), config.p2);
      pname = config.p2;
    } else if (ao == 2) {
      myNex.writeStr(F("tnextp.txt"), config.p3);
      pname = config.p3;
    } else if (ao == 3) {
      myNex.writeStr(F("tnextp.txt"), config.p4);
      pname = config.p4;
    } else if (ao == 4) {
      myNex.writeStr(F("tnextp.txt"), config.p5);
      pname = config.p5;
    }
    inform(1, 1, 10);
    int oTargets = config.targets;
    int currentPort = random(oTargets);
    int newPort = random(oTargets);
    int sendAway = 0;
    int missTarget = 0;
    int hitCounter = 0;
    unsigned long time1;
    unsigned long time2;
    float interval1;
    long startTime, stopTime;
    int oRounds;
    float timedRun;
    if (g == 1) {
      myNex.writeStr(F("page page3"));
      oRounds = config.maxrounds;
    } else if (g == 2) {
      myNex.writeStr(F("page page9"));
      interval1 = 0;
      timedRun = (float)config.timed;
    } else {
      myNex.writeStr(F("page page10"));
      oRounds = config.maxrapid;
    }
    delay(500);
    randomSeed(millis());
    if (g == 3 || g == 2) {
      time1 = millis();
    }
    if (g == 1 || g == 3) {
      for (int i = 0; i < oRounds; i++) {
        if (g == 1) {
          myNex.writeStr(F("tround.txt"), String(i + 1));
          delay(random(3000) + 1000);
          time1 = millis();
        }
        totarget.I = config.targID[currentPort];
        totarget.J = 1;
        fromtarget.K = config.recID[currentPort];
        sendAway = 1;
        myRadio.stopListening();
        delay(100);
        myRadio.write(&totarget, sizeof(totarget));
        delay(100);
        myRadio.startListening();
        startTime = millis();
        while (sendAway == 1) {
          stopTime = millis();
          if (stopTime - startTime >= config.safetime) {
            sendAway = 0;
            missTarget = 1;
          }
          if (myRadio.available(addresses[0])) {
            myRadio.read(&fromtarget, sizeof(fromtarget));
            if (fromtarget.K == config.recID[currentPort]) {
              myNex.writeStr("page18.bbt" + String(currentPort) + ".txt", String(fromtarget.O));
              if (fromtarget.L == 2) {
                missTarget = 1;
              }
              sendAway = 0;
            }
          }
        }
        if (missTarget == 1) {
          missTarget = 0;
          i = i - 1;
          if (g == 3) {
            newPort = random(oTargets);
            while (newPort == currentPort)
              newPort = random(oTargets);
            currentPort = newPort;
          }
        } else {
          if (g == 1) {
            time2 = millis();
            interval1 = (time2 - time1);
            interval1 = interval1 / 1000;
            myNex.writeStr(F("trtime.txt"), String(interval1));
            myNex.writeStr("page12.rrq" + String(i + 1) + ".txt", String(interval1));
            savehigh(1, interval1, pname, 0);
          } else {
            newPort = random(oTargets);
            while (newPort == currentPort)
              newPort = random(oTargets);
            currentPort = newPort;
          }
        }
        if (g == 1) {
          newPort = random(oTargets);
          while (newPort == currentPort)
            newPort = random(oTargets);
          currentPort = newPort;
        }
      }
      if (g == 3) {
        time2 = millis();
        interval1 = (time2 - time1);
        interval1 = interval1 / 1000;
        myNex.writeStr(F("page14.rtrap1.txt"), String(interval1));
        savehigh(3, interval1, pname, 0);
        myNex.writeStr(F("page page14"));
        delay(20000);
      } else {
        myNex.writeStr(F("page page12"));
        delay(20000);
      }

    } else {
      while (interval1 < timedRun) {
        totarget.I = config.targID[currentPort];
        totarget.J = 1;
        fromtarget.K = config.recID[currentPort];
        sendAway = 1;
        myRadio.stopListening();
        delay(100);
        myRadio.write(&totarget, sizeof(totarget));
        delay(100);
        myRadio.startListening();
        startTime = millis();
        while (sendAway == 1) {
          stopTime = millis();
          if (stopTime - startTime >= config.safetime) {
            sendAway = 0;
            missTarget = 1;
          }
          if (myRadio.available(addresses[0])) {
            myRadio.read(&fromtarget, sizeof(fromtarget));
            if (fromtarget.K == config.recID[currentPort]) {
              myNex.writeStr("page18.bbt" + String(currentPort) + ".txt", String(fromtarget.O));
              if (fromtarget.L == 2) {
                missTarget = 1;
              }
              sendAway = 0;
            }
          }
        }
        if (missTarget == 1) {
          missTarget = 0;
          time2 = millis();
          interval1 = (time2 - time1);
        } else {
          hitCounter++;
          time2 = millis();
          interval1 = (time2 - time1);
          myNex.writeStr(F("thits.txt"), String(hitCounter));
          myNex.writeStr(F("page13.rtih1.txt"), String(hitCounter));
          savehigh(2, interval1, pname, hitCounter);
        }
        newPort = random(oTargets);
        while (newPort == currentPort)
          newPort = random(oTargets);
        currentPort = newPort;
      }
      myNex.writeStr(F("page page13"));
      delay(20000);
    }
  }
  myNex.writeStr(F("page page1"));
}

void savehigh(int game, float time, String play, int hits) {
  DateTime now = rtc.now();
  if (game == 1) {
    //Quicktime
    if (config.hq[0] == 0) {
      config.hq[0] = time;
      play.toCharArray(config.hp1, 11);
      //ddate.toCharArray(config.hd1, 11);
      sprintf(config.hd1, "%04d-%02d-%02d %02d:%02d", now.year(), now.month(), now.day(), now.hour(), now.minute());
    } else if (time < config.hq[0]) {
      config.hq[0] = time;
      play.toCharArray(config.hp1, 11);
      sprintf(config.hd1, "%04d-%02d-%02d %02d:%02d", now.year(), now.month(), now.day(), now.hour(), now.minute());
    }
  } else if (game == 2) {
    //Timed
    if (hits > config.hr) {
      config.hr = hits;
      play.toCharArray(config.hp2, 11);
      sprintf(config.hd2, "%04d-%02d-%02d %02d:%02d", now.year(), now.month(), now.day(), now.hour(), now.minute());
    }
  } else {
    //Rapid
    if (config.hq[1] == 0) {
      config.hq[1] = time;
      play.toCharArray(config.hp3, 11);
      sprintf(config.hd3, "%04d-%02d-%02d %02d:%02d", now.year(), now.month(), now.day(), now.hour(), now.minute());
    } else if (time < config.hq[1]) {
      config.hq[1] = time;
      play.toCharArray(config.hp3, 11);
      sprintf(config.hd3, "%04d-%02d-%02d %02d:%02d", now.year(), now.month(), now.day(), now.hour(), now.minute());
    }
  }
  conf(1);
}

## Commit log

2023-01-15 Added image of PCB for target
    The first layout of pcb for target sensor board.
2023-01-17 Added Schematic for main unit
2023-01-21 New version of target sensor
2023-02-05 Added the program to target sensor
2023-09-06 Added Y2 Crystal kHz
    [bomlistall.csv]
